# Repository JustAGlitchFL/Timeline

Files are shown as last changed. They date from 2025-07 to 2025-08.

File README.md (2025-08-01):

# Timeline
Video/photo editing keyboard tuned for Davinci Resolve

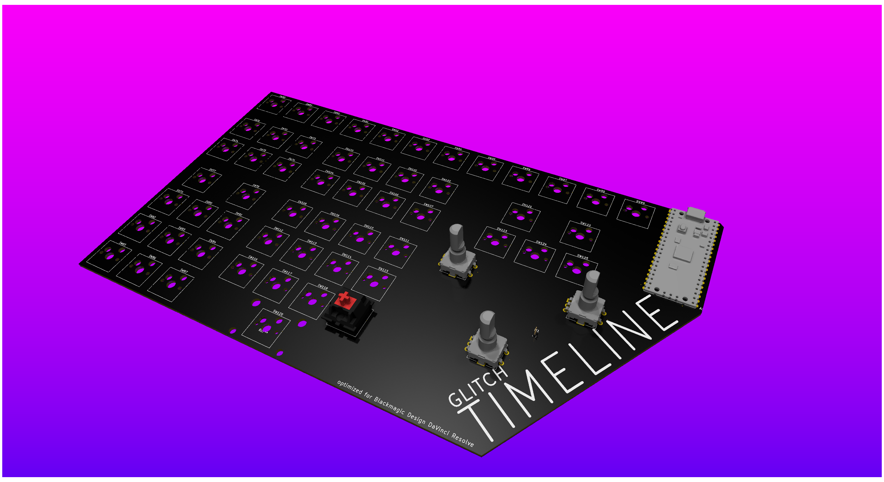
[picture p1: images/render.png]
render

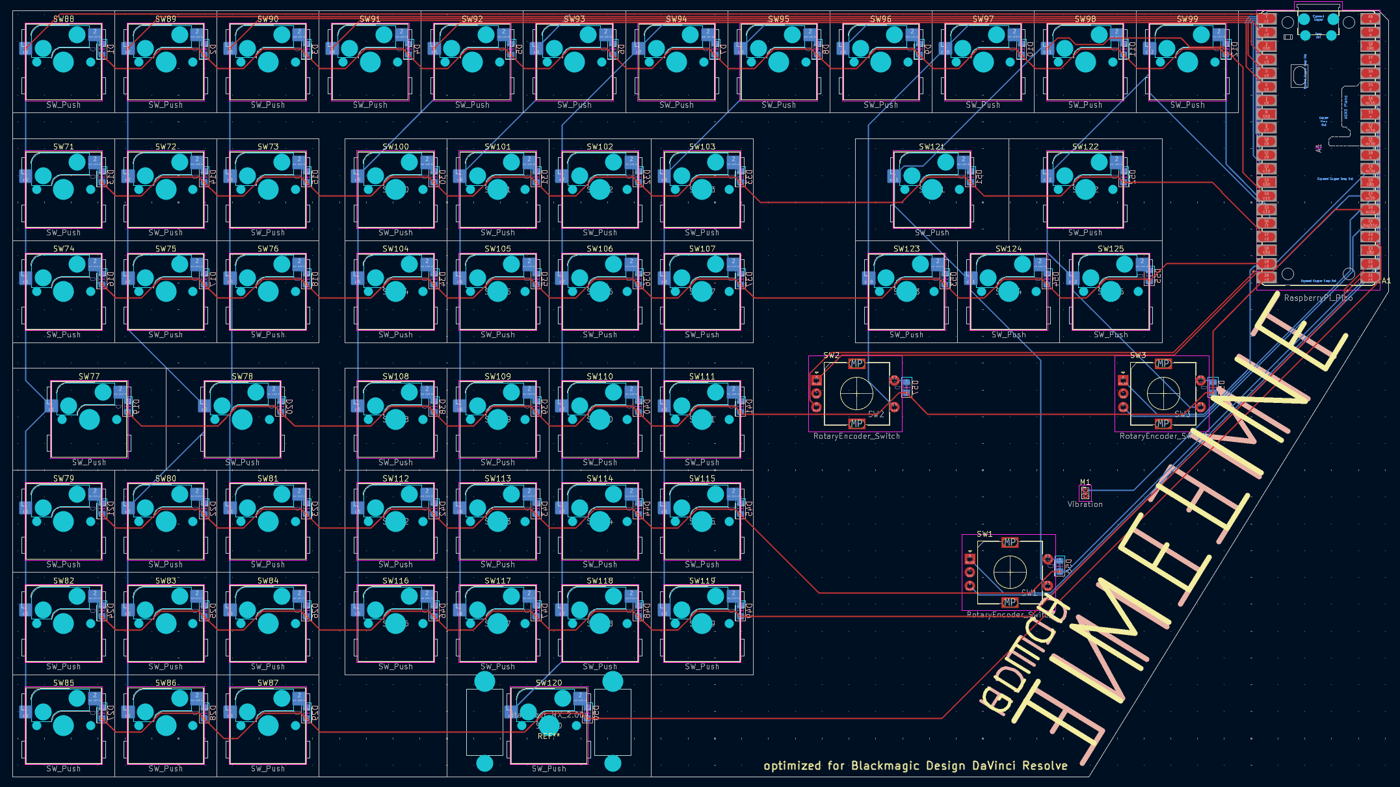
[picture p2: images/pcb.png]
pcb

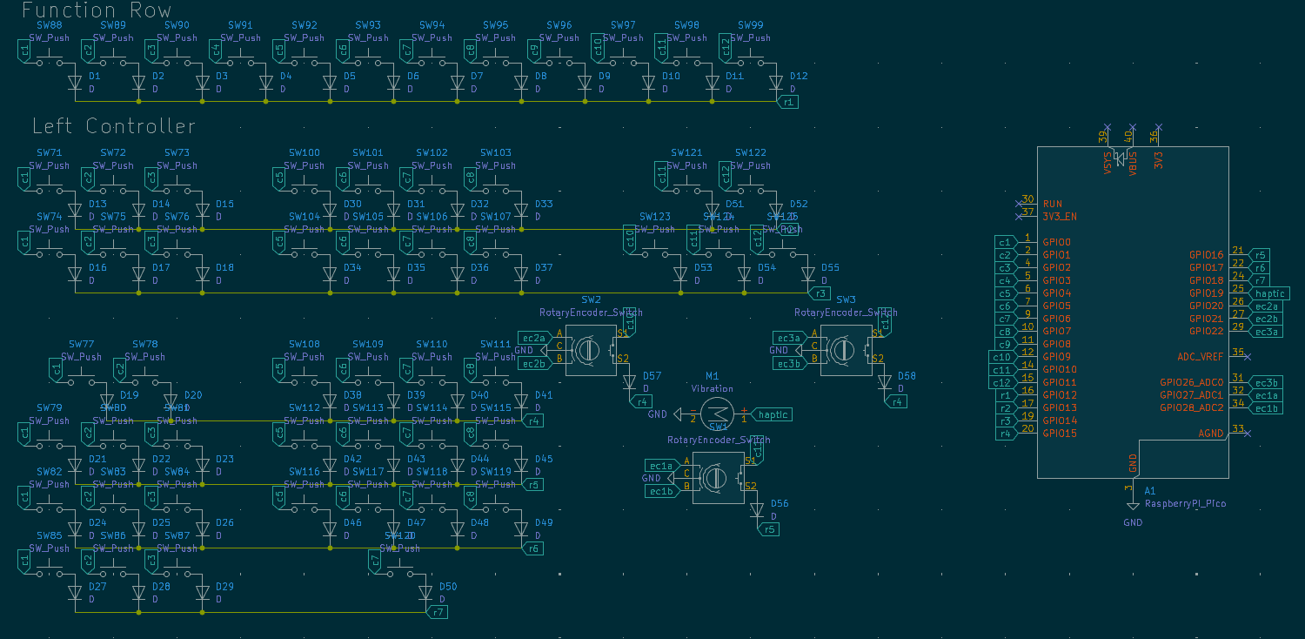
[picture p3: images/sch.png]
sch


## Why
I edit in Blackmagic Design DaVinci Resolve, and would like to have something a little smoother than a keyboard and mouse. BD sells the Speed Editor, but it costs US$435, which is kinda insane. 
speed editor
I felt I might as well make my own version of this, so I created this as a largely 1:1 clone of the layout with a custom design

## Assembly/Other info
This does not include a case, as I wanted to keep it low to the table, and to keep the bare PCB aesthetic I enjoy. Solder the parts as they fit into the board, then apply some 3M 2229 to the bottom of the board to resuce sliding, and to protect the board/desk.  

## BOM
|q  |part |link |price |total |
|---|---|---|---|---|
|1  |pcb | |$45.70 |$72.86|
|55 |switches | |have on hand| |
|2  |ECE11 with clicks|https://www.mouser.com/ProductDetail/688-EC11E15204A3 |$7.36 | |
|1  |Smooth EC11 |https://www.mouser.com/ProductDetail/688-EC11E1834403 |$4.68 | |
| |Vibration Motor  |https://www.mouser.com/ProductDetail/665-HD-EM0802-LW30-R|$3.93 | |
| |mouser shipping  | |$7.99 | |
| |mouser DDP | |$3.20 | |

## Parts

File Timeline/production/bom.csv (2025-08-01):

Designator | Footprint | Quantity | Value | LCSC Part #
A1 | RaspberryPi_Pico_Common_SMD noantenna | 1 | RaspberryPi_Pico
D1, D10, D11, D12, D13, D14, D15, D16, D17, D18, D19, D2, D20, D21, D22, D23, D24, D25, D26, D27, D28, D29, D3, D30, D31, D32, D33, D34, D35, D36, D37, D38, D39, D4, D40, D41, D42, D43, D44, D45, D46, D47, D48, D49, D5, D50, D51, D52, D53, D54, D55, D56, D57, D58, D6, D7, D8, D9 | 0805 | 58 | D
M1 | PinHeader_1x02_P1.00mm_Vertical | 1 | Vibration
SW1, SW2, SW3 | RotaryEncoder_Alps_EC11E-Switch_Vertical_H20mm | 3 | RotaryEncoder_Switch
SW100, SW101, SW102, SW103, SW104, SW105, SW106, SW107, SW108, SW109, SW110, SW111, SW112, SW113, SW114, SW115, SW116, SW117, SW118, SW119, SW123, SW124, SW125, SW71, SW72, SW73, SW74, SW75, SW76, SW79, SW80, SW81, SW82, SW83, SW84, SW85, SW86, SW87, SW88, SW89, SW90, SW91, SW92, SW93, SW94, SW95, SW96, SW97, SW98, SW99 | Hotswap_MX_1.00u | 50 | SW_Push
SW120 | Hotswap_MX_2.00u | 1 | SW_Push
SW121, SW122, SW77, SW78 | Hotswap_MX_1.50u | 4 | SW_Push

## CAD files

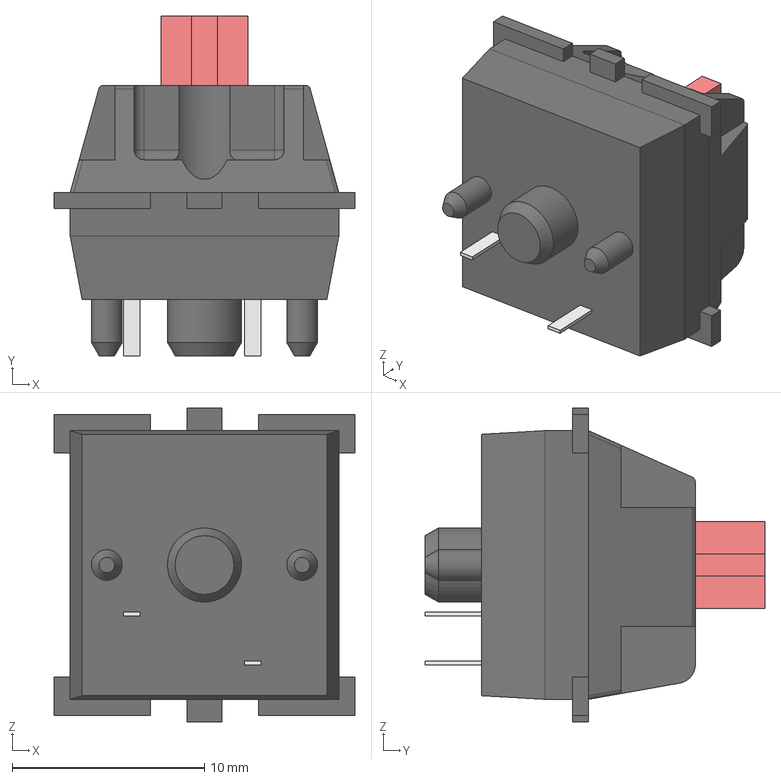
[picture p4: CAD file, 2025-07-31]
Timeline/switch.step
15.6 x 17.7 x 16.3 mm

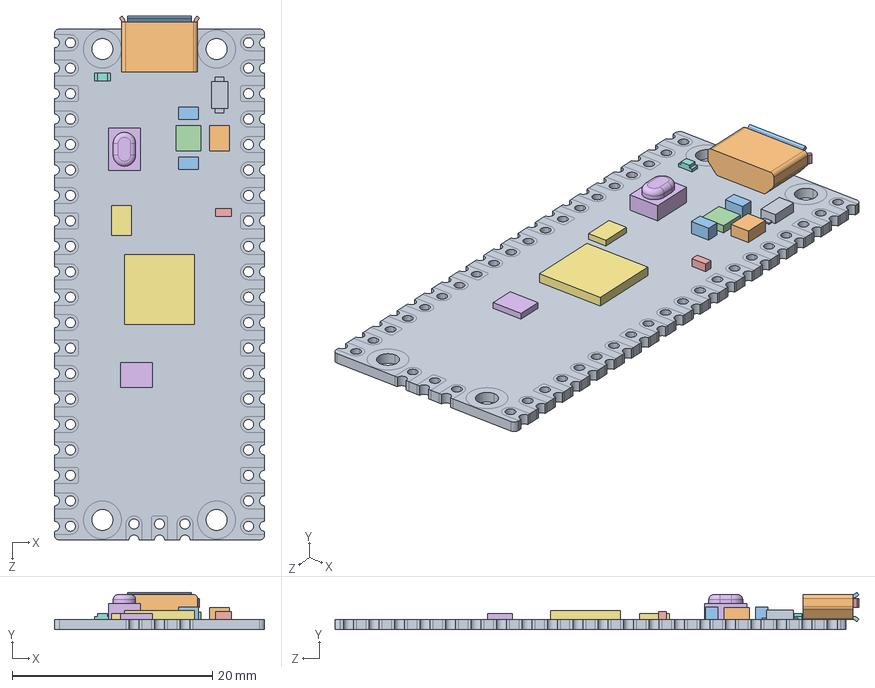
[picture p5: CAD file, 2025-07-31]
Timeline/Pico-R3.step
21.0 x 3.73 x 52.3 mm
PICO_REF_BOARD.STEP
PICO_REF_USB.STEP
PICO_REF_SWITCH.STEP
PICO_REF_MICROCONTROLLER.STEP
PICO_REF_LED.STEP
PICO_REF_ONSEMI.STEP
PICO_BOURNS.STEP
PICO_MURATA.STEP x 2
PICO_RICHTEK.STEP
PICO_DIODES.STEP
PICO_AEL.STEP
PICO_WINBOND.STEP

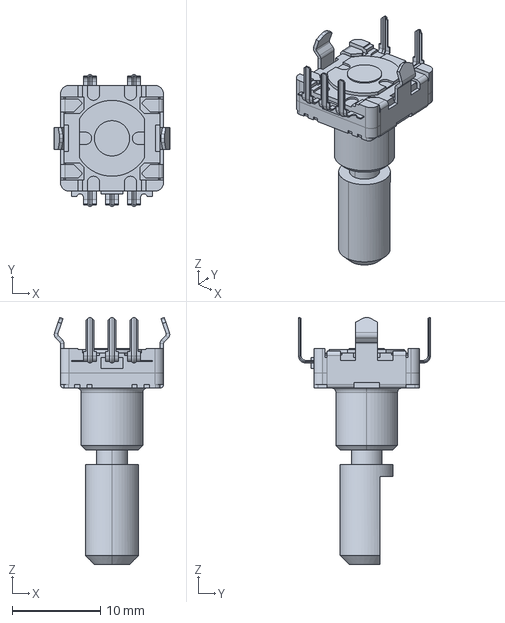
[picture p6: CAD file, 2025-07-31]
Timeline/ec11e09244aq.stp
13.1 x 15.0 x 28.0 mm

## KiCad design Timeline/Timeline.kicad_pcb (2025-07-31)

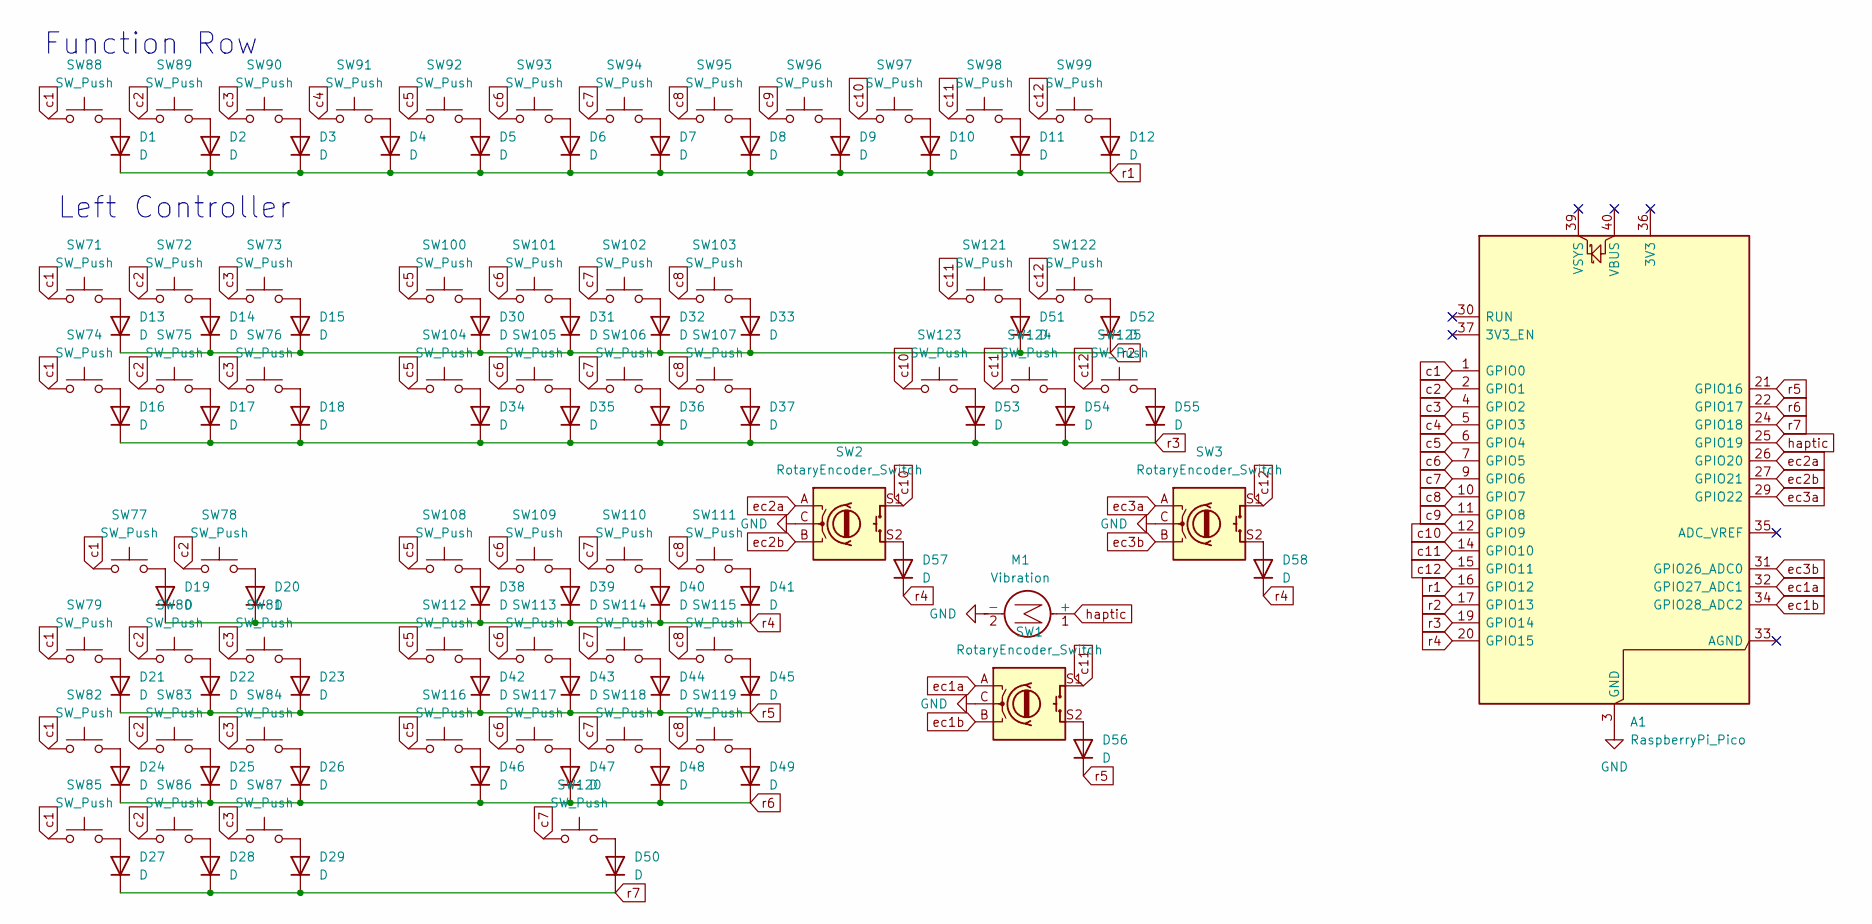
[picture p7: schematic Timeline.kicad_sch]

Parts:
A1: RaspberryPi_Pico; RaspberryPi_Pico_Common_SMD noantenna
D1, D2, D3, D4, D5, D6, D7, D8, D9, D10, D11, D12, D13, D14, D15, D16, D17, D18, D19, D20, D21, D22, D23, D24, D25, D26, D27, D28, D29, D30, D31, D32, D33, D34, D35, D36, D37, D38, D39, D40, D41, D42, D43, D44, D45, D46, D47, D48, D49, D50, D51, D52, D53, D54, D55, D56, D57, D58: D; D_0805_2012Metric_Pad1.15x1.40mm_HandSolder
M1: Vibration; PinHeader_1x02_P1.00mm_Vertical
SW1, SW2, SW3: RotaryEncoder_Switch; RotaryEncoder_Alps_EC11E-Switch_Vertical_H20mm
SW71, SW72, SW73, SW74, SW75, SW76, SW79, SW80, SW81, SW82, SW83, SW84, SW85, SW86, SW87, SW88, SW89, SW90, SW91, SW92, SW93, SW94, SW95, SW96, SW97, SW98, SW99, SW100, SW101, SW102, SW103, SW104, SW105, SW106, SW107, SW108, SW109, SW110, SW111, SW112, SW113, SW114, SW115, SW116, SW117, SW118, SW119, SW123, SW124, SW125: SW_Push; Hotswap_MX_1.00u
SW77, SW78, SW121, SW122: SW_Push; Hotswap_MX_1.50u
SW120: SW_Push; Hotswap_MX_2.00u

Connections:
GND: A1.3 (GND), A1.8 (GND), A1.13 (GND), A1.18 (GND), A1.23 (GND), A1.28 (GND), A1.38 (GND), M1.2 (-), SW1.C, SW2.C, SW3.C
unnamed: D1.2 (A), SW88.2
unnamed: D2.2 (A), SW89.2
unnamed: D3.2 (A), SW90.2
unnamed: D4.2 (A), SW91.2
unnamed: D5.2 (A), SW92.2
unnamed: D6.2 (A), SW93.2
unnamed: D7.2 (A), SW94.2
unnamed: D8.2 (A), SW95.2
unnamed: D9.2 (A), SW96.2
unnamed: D10.2 (A), SW97.2
unnamed: D11.2 (A), SW98.2
unnamed: D12.2 (A), SW99.2
unnamed: D13.2 (A), SW71.2
unnamed: D14.2 (A), SW72.2
unnamed: D15.2 (A), SW73.2
unnamed: D16.2 (A), SW74.2
unnamed: D17.2 (A), SW75.2
unnamed: D18.2 (A), SW76.2
unnamed: D19.2 (A), SW77.2
unnamed: D20.2 (A), SW78.2
unnamed: D21.2 (A), SW79.2
unnamed: D22.2 (A), SW80.2
unnamed: D23.2 (A), SW81.2
unnamed: D24.2 (A), SW82.2
unnamed: D25.2 (A), SW83.2
unnamed: D26.2 (A), SW84.2
unnamed: D27.2 (A), SW85.2
unnamed: D28.2 (A), SW86.2
unnamed: D29.2 (A), SW87.2
unnamed: D30.2 (A), SW100.2
unnamed: D31.2 (A), SW101.2
unnamed: D32.2 (A), SW102.2
unnamed: D33.2 (A), SW103.2
unnamed: D34.2 (A), SW104.2
unnamed: D35.2 (A), SW105.2
unnamed: D36.2 (A), SW106.2
unnamed: D37.2 (A), SW107.2
unnamed: D38.2 (A), SW108.2
unnamed: D39.2 (A), SW109.2
unnamed: D40.2 (A), SW110.2
unnamed: D41.2 (A), SW111.2
unnamed: D42.2 (A), SW112.2
unnamed: D43.2 (A), SW113.2
unnamed: D44.2 (A), SW114.2
unnamed: D45.2 (A), SW115.2
unnamed: D46.2 (A), SW116.2
unnamed: D47.2 (A), SW117.2
unnamed: D48.2 (A), SW118.2
unnamed: D49.2 (A), SW119.2
unnamed: D50.2 (A), SW120.2
unnamed: D51.2 (A), SW121.2
unnamed: D52.2 (A), SW122.2
unnamed: D53.2 (A), SW123.2
unnamed: D54.2 (A), SW124.2
unnamed: D55.2 (A), SW125.2
unnamed: D56.2 (A), SW1.S2
unnamed: D57.2 (A), SW2.S2
unnamed: D58.2 (A), SW3.S2
c1: A1.1 (GPIO0), SW71.1, SW74.1, SW77.1, SW79.1, SW82.1, SW85.1, SW88.1
c2: A1.2 (GPIO1), SW72.1, SW75.1, SW78.1, SW80.1, SW83.1, SW86.1, SW89.1
c3: A1.4 (GPIO2), SW73.1, SW76.1, SW81.1, SW84.1, SW87.1, SW90.1
c4: A1.5 (GPIO3), SW91.1
c5: A1.6 (GPIO4), SW92.1, SW100.1, SW104.1, SW108.1, SW112.1, SW116.1
c6: A1.7 (GPIO5), SW93.1, SW101.1, SW105.1, SW109.1, SW113.1, SW117.1
c7: A1.9 (GPIO6), SW94.1, SW102.1, SW106.1, SW110.1, SW114.1, SW118.1, SW120.1
c8: A1.10 (GPIO7), SW95.1, SW103.1, SW107.1, SW111.1, SW115.1, SW119.1
c9: A1.11 (GPIO8), SW96.1
c10: A1.12 (GPIO9), SW2.S1, SW97.1, SW123.1
c11: A1.14 (GPIO10), SW1.S1, SW98.1, SW121.1, SW124.1
c12: A1.15 (GPIO11), SW3.S1, SW99.1, SW122.1, SW125.1
ec1a: A1.32 (GPIO27_ADC1), SW1.A
ec1b: A1.34 (GPIO28_ADC2), SW1.B
ec2a: A1.26 (GPIO20), SW2.A
ec2b: A1.27 (GPIO21), SW2.B
ec3a: A1.29 (GPIO22), SW3.A
ec3b: A1.31 (GPIO26_ADC0), SW3.B
haptic: A1.25 (GPIO19), M1.1 (+)
r1: A1.16 (GPIO12), D1.1 (K), D2.1 (K), D3.1 (K), D4.1 (K), D5.1 (K), D6.1 (K), D7.1 (K), D8.1 (K), D9.1 (K), D10.1 (K), D11.1 (K), D12.1 (K)
r2: A1.17 (GPIO13), D13.1 (K), D14.1 (K), D15.1 (K), D30.1 (K), D31.1 (K), D32.1 (K), D33.1 (K), D51.1 (K), D52.1 (K)
r3: A1.19 (GPIO14), D16.1 (K), D17.1 (K), D18.1 (K), D34.1 (K), D35.1 (K), D36.1 (K), D37.1 (K), D53.1 (K), D54.1 (K), D55.1 (K)
r4: A1.20 (GPIO15), D19.1 (K), D20.1 (K), D38.1 (K), D39.1 (K), D40.1 (K), D41.1 (K), D57.1 (K), D58.1 (K)
r5: A1.21 (GPIO16), D21.1 (K), D22.1 (K), D23.1 (K), D42.1 (K), D43.1 (K), D44.1 (K), D45.1 (K), D56.1 (K)
r6: A1.22 (GPIO17), D24.1 (K), D25.1 (K), D26.1 (K), D46.1 (K), D47.1 (K), D48.1 (K), D49.1 (K)
r7: A1.24 (GPIO18), D27.1 (K), D28.1 (K), D29.1 (K), D50.1 (K)

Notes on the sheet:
Left Controller
Function Row

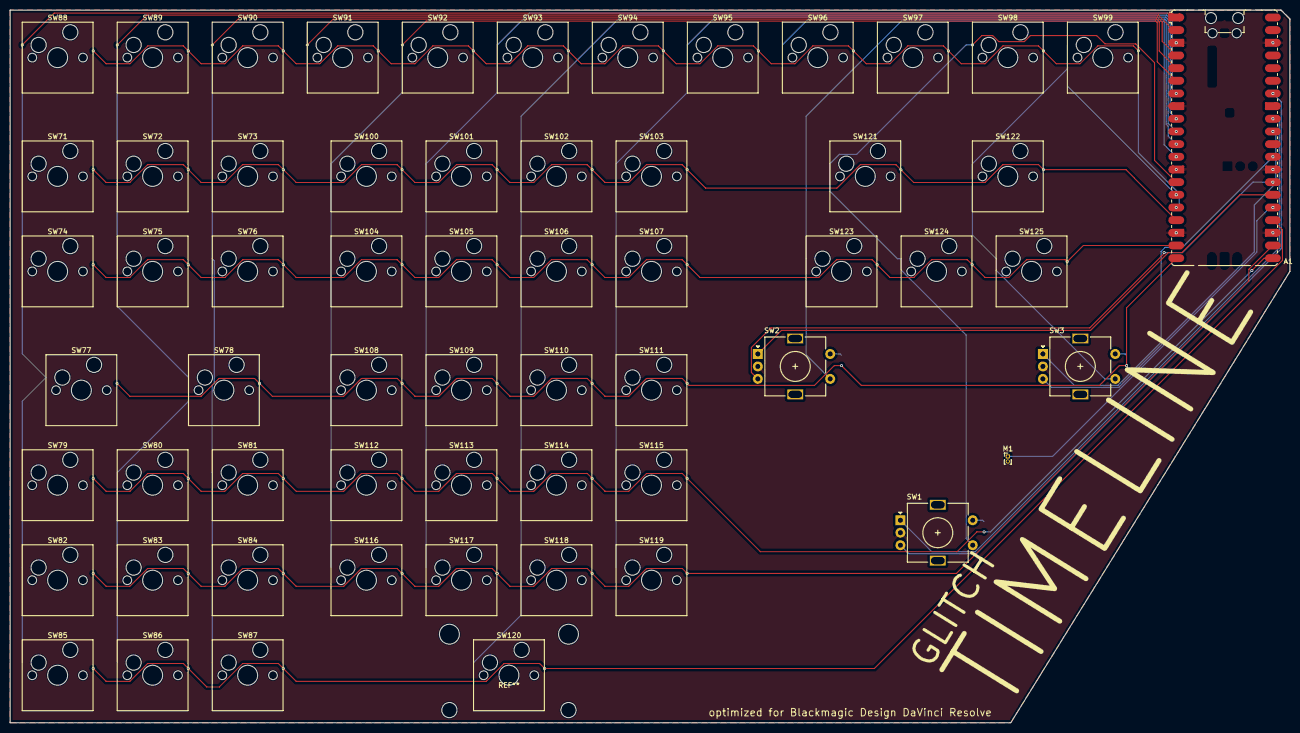
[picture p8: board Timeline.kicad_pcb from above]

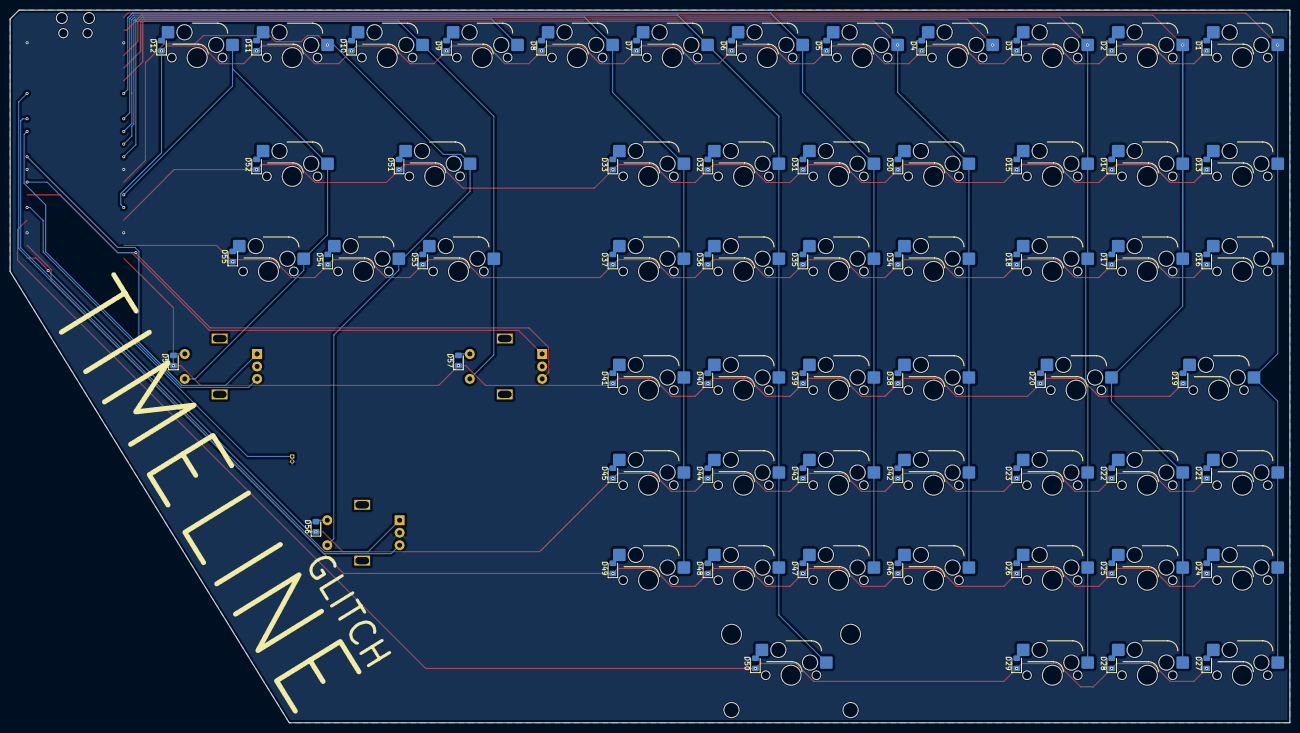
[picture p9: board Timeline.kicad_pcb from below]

Board: 2 copper layers, 256.6 x 142.9 mm, 118 parts (58 on the bottom side), 85 nets.

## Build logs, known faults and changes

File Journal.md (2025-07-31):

---
title: "Timeline"
author: "rowyn"
description: "Video/photo editing keyboard tuned for Davinci Resolve"
created_at: "2024-07/22"
---
Total hours: 9 

## 7/22: Ideation and planning
I found the DaVinci speed editor, and realized that it would be quite helpful for large-scale video projects, but I did not want to spend $435 on it. I laid out a rough map of the key layout in the schematic editor to see how feasible a clone of it would be, and decided to move forward with this project.

Hours: 2

## 7/23: Putting the schematic together
Exactly what it says on the tin, laid out my matrix and connected it up. I also had the idea to include a small linear vibration motor to add haptic feedback when snapping the knob onto each clip. Combined with a smooth EC11, this will allow for a fast yet precise editing experience.

sch

Hours:2 

## 7/28: PCB and part sourcing
I mapped everything onto the pcb layout, and routed it. I also found which vibration motor to use, and laid out my part sourcing for everything.

pcb

Hours: 3

## 7/30: 3d models
I found out that you still need to include component models regardless of whether you're making a case, so I found and imported them. However, I could not figure out a way to retroactively apply them to all of the keyswitches, so I just included 1 as a sample. I'm not concerned about any part interaction, as I'm not making a case for this at this time (maybe later when I have access to a functional 3d printer idek).

render

Hours: 1

## 7/31: last minute submission

Putting it all together and submitting before the deadline.

Hours: 1
